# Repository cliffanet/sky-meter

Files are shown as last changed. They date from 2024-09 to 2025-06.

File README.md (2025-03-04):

# Высотомер Sky-Meter

Инструмент для парашютиста - простой высотомер на базе барометра.

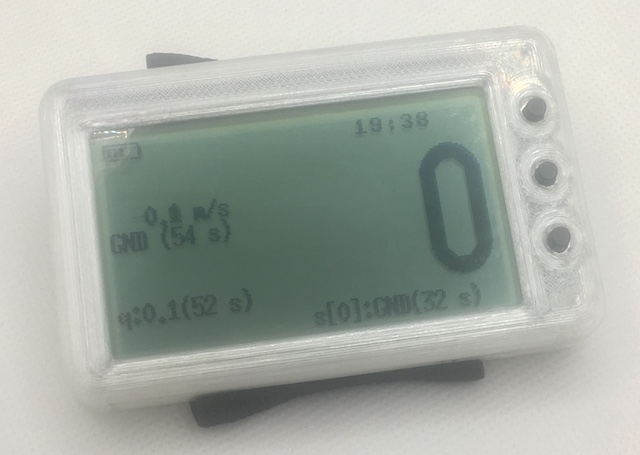
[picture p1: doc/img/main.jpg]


***
## Что умеет

* измерять высоту;
* определять начала подъёма и начало прыжка;
* писать в логбук историю прыжков: время взлёта, высота отделения, высота раскрытия;

***
## Внутри

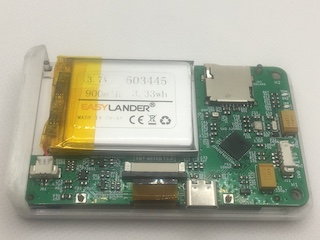
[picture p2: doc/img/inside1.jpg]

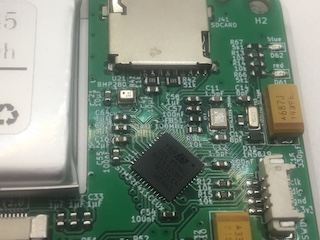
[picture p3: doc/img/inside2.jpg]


***
## Документация

* [Исходники](doc/code.md) - где, что лежит, права на использование, помощь при компиляции.
* [Где скачать](doc/download.md)

***
## Известные проблемы

- повышенное энергопотребление в спящем режиме (850 мкА)

    В первой аппаратной версии применялся чип stm32f473 и энергопотребление всего устройства
    на его основе удалось снизить до 125 мкА, а в выключенном - до 85-90 мкА. И это
    при заявленных в документации 56 мкА (что-то дополнительно подребляет и сама плата).

    А вот на чипе stm32f411 при заявленных в документации 10 мкА получить потребление ниже
    60 мкА так и не удалось - но это на пустой прошивке. На боевой же прошивке почему-то
    не отключаются какие-то узлы, и потребление ~850 мкА. С этим ещё предстоит разобраться.

- нестабильная работа с SD-картой

    Проблема возникает из-за слабого питания, подаваемого на карту. В целях экономии заряда
    батареи питание на SD-карту выведено напрямую с пина микроконтроллера. Применение дополнительного
    транзистора в режиме ключа вызывает проблемы из-за низкого потребляемого тока карты (несколько мА).
    При инициализации карты ток возрастает и питание проседает, из-за чего карта сбрасывается.

    Некоторые карты всё же работают, но таких мало.

    На stm32g4xx работа карт от пина была гораздо стабильнее. Но всё же, на некоторых картах тоже
    были сбои.

    В качестве оперативной меры можно перерезать дорожку, ведущую к пину МК и соединить питание карты
    напрямую на 3.3v. Однако потребление в спящем режиме вместе с SD-картой возрастает до 3 мА.

- отсутствие приложения для импорта логбука

    Разработка отложена на неопределённый срок.

***

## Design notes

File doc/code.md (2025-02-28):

# sky-meter - Исходники

## Открытость проекта

Проект полностью открыт. Закрывать - не планирую. На коммерческую основу ставить - не планирую.

[Репозиторий на github.com](https://github.com/cliffanet/sky-meter)

## Можно ли использовать исходники в своих проектах

Да, никаких возражений против использования исходного кода в своих проектах. Однако, будет лучше, если вы будете ссылаться на использование данного проекта. Это один из важных мотивационных факторов к дальнейшему развитию.

Это относится и к любительским проектам, и к крупным бесплатным, и к коммерческим.

## Где и что находится

* Исходный код прошивки

    Директория [`cube`](https://github.com/cliffanet/sky-meter/tree/master/cube).
    Оптимизировано для среды [STM32CubeMX](https://www.st.com/en/development-tools/stm32cubemx.html).

    - [Как прошить](download.md#обновление-прошивки)
    - [Самостоятельно собрать прошивку](#компиляция-сборка-прошивки-с-помощью-cubemx)

* Исходники электрической схемы и печатной платы

    Всё находится в директории [`hw`](https://github.com/cliffanet/sky-meter/tree/master/hw).
    Среда разработки: [KiCad EDA](https://www.kicad.org/)

    - [Архив с gerber-файлами](../hw/v2.0/sky-meter.v2.0.zip)
    - [Схема принципиальная](../hw/v2.0/sky-meter.v2.0.png)

 

* Исходники 3D-моделей для печати корпуса

    Директория [`box`](https://github.com/cliffanet/sky-meter/tree/master/box).
    Среда: [FreeCAD](https://www.freecad.org/)
    
    Тут же лежат экспортированные в `stl` файлы моделей. В имени файлов зашифровано:
    
    * `top` / `bottom` - верхняя и нижняя часть корпуса.

## Электронные компоненты:

* Дисплей JLX19292G: COG 192x96 на чипе ST75256 c 24-pin шлейфом ([например](https://aliexpress.ru/item/1005002157371258.html))
* Аккумулятор: 503445 900 mAh ([например](https://aliexpress.ru/item/4000288981646.html))
* Микроконтроллер: STM32F411CEU6

## Компиляция (сборка) прошивки с помощью CubeMX

Необходимые пакеты и программы:

- [STM32CubeMX](https://www.st.com/en/development-tools/stm32cubemx.html)

- [arm-none-eabi-gcc](https://developer.arm.com/downloads/-/gnu-rm)

    Для MacOS используйте:

    ```
    brew install --cask gcc-arm-embedded
    ```

- утилита make

Исходный код находится в директории [cube](../cube).

1. Переходим в директорию [cube](../cube).

2. Копируем файл Makefile.stm32f411 в Makefile

3. Открываем файл [sky-meter.stm32f411ceu.ioc](../cube/sky-meter.stm32f411ceu.ioc) в CubeMX.

4. Жмём кнопку "Generate Code".

5. Скачиваем [драйвер SD-карты](http://elm-chan.org/fsw/ff/arc/ff15a.zip) с сайта [elm-chan.org](http://elm-chan.org).

    - берём оттуда только директорию: source
    - переименовываем её в: ff
    - копируем в нашу директорию: [cube/source](../cube/source)
    - удаляем файл cube/source/ff/diskio.c

6. Скачиваем [драйвер дисплея](https://github.com/olikraus/u8g2)

    - берём оттуда только директорию: csrc
    - переименовываем её в: u8g2
    - копируем в нашу директорию: [cube/source](../cube/source)

7. Запускаем командную строку (терминал) в этой же директории.

8. Выполняем:

        make

9. Если всё скомпилировалось успешно, во вложенной директории build будет лежать файл sky-meter.stm32f411ceu.bin

[Инструкция по обновлению прошивки](download.md#обновление-прошивки)

Чтобы изменить язык меню:

    make VLANG=R

или:

    make VLANG=E

## Предыдущая аппаратная версия

- [плата v1.0](../hw/v1.0/sky-meter.v1.0.zip)
- CubeMX файлы:
    - [sky-meter.stm32g431cbu.ioc](../cube/sky-meter.stm32g431cbu.ioc) и [Makefile.stm32g431](../cube/Makefile.stm32g431)
    - [sky-meter.stm32g473ceu.ioc](../cube/sky-meter.stm32g473ceu.ioc) и [Makefile.stm32g473](../cube/Makefile.stm32g473)

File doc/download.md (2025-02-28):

# Скачивание файлов

Стабильная версия прошивки:

* RU: [sky-meter.stm32f411ceu.v1.00.ru.bin](https://github.com/cliffanet/sky-meter/releases/download/v1.00/sky-meter.stm32f411ceu.v1.00.ru.bin)
* EN: [sky-meter.stm32f411ceu.v1.00.en.bin](https://github.com/cliffanet/sky-meter/releases/download/v1.00/sky-meter.stm32f411ceu.v1.00.en.bin)

## Обновление прошивки

Неодходимое оборудование:

- SWD-кабель

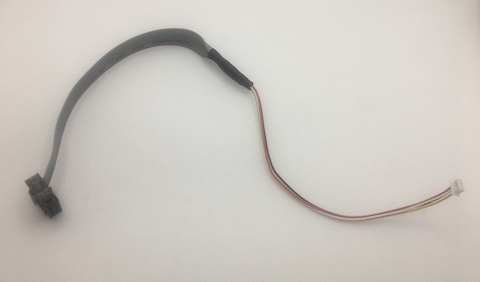
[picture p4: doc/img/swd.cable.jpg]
    

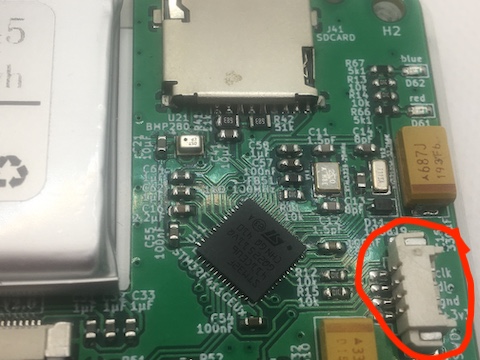
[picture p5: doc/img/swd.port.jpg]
    

- программатор ST-Link v.2

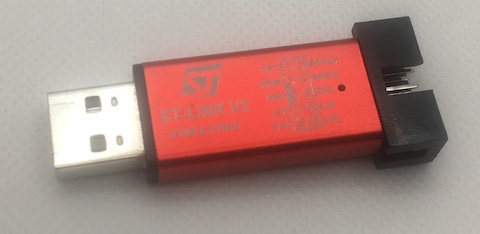
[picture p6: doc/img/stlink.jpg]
    

- [Утилита взаимодействия по SWD-порту](https://www.st.com/en/development-tools/stm32cubeprog.html)

## История версий

[История версий и самые свежие файлы](https://github.com/cliffanet/sky-meter/releases)

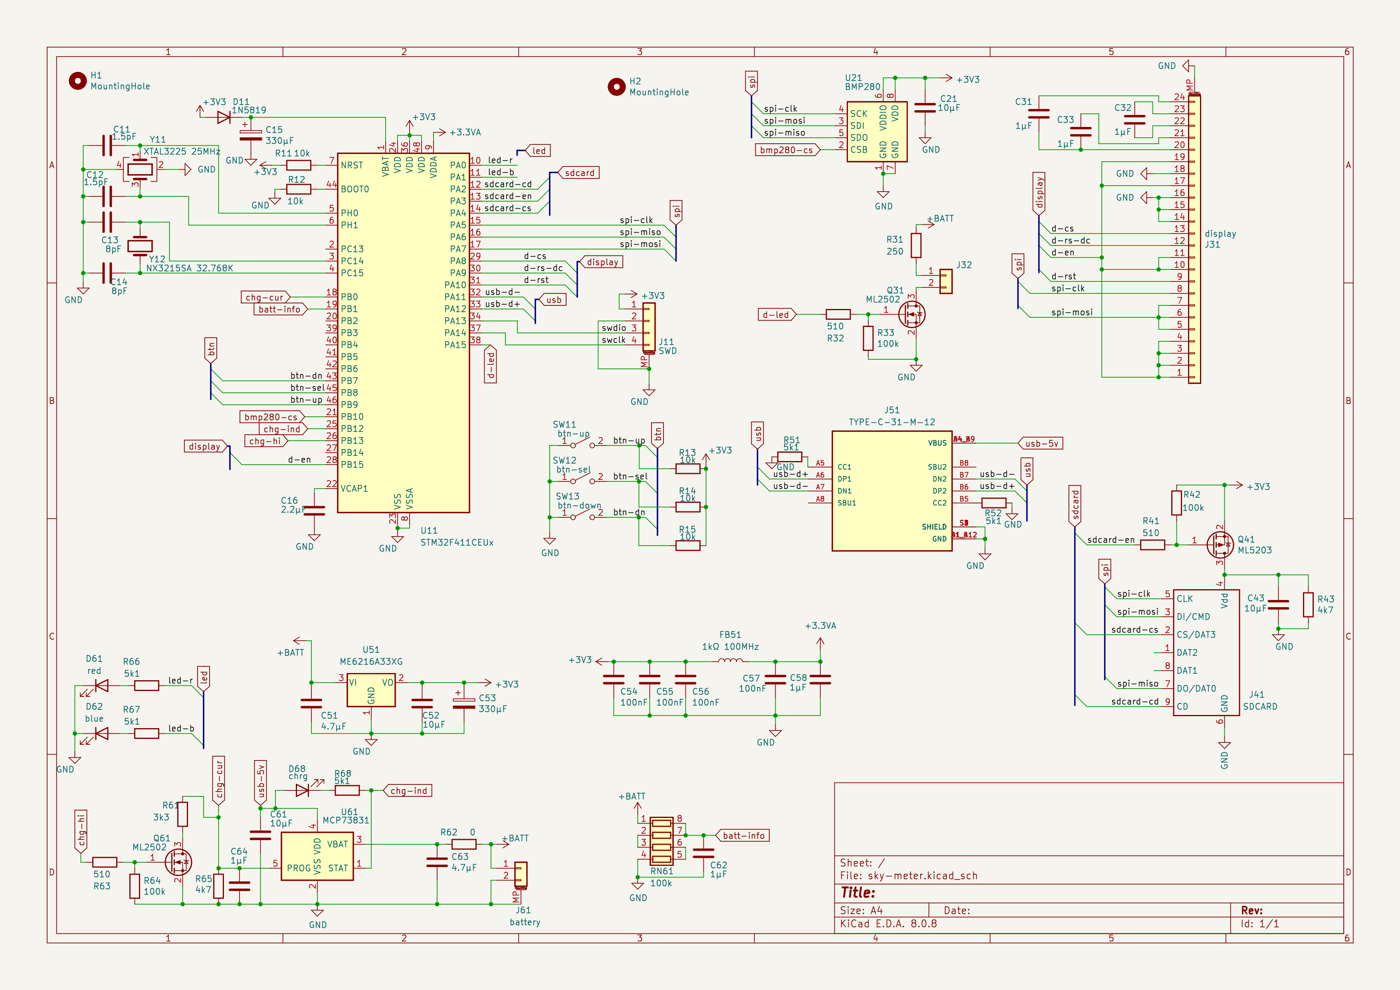
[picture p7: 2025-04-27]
hw/v2.1/sky-meter.v2.1.png

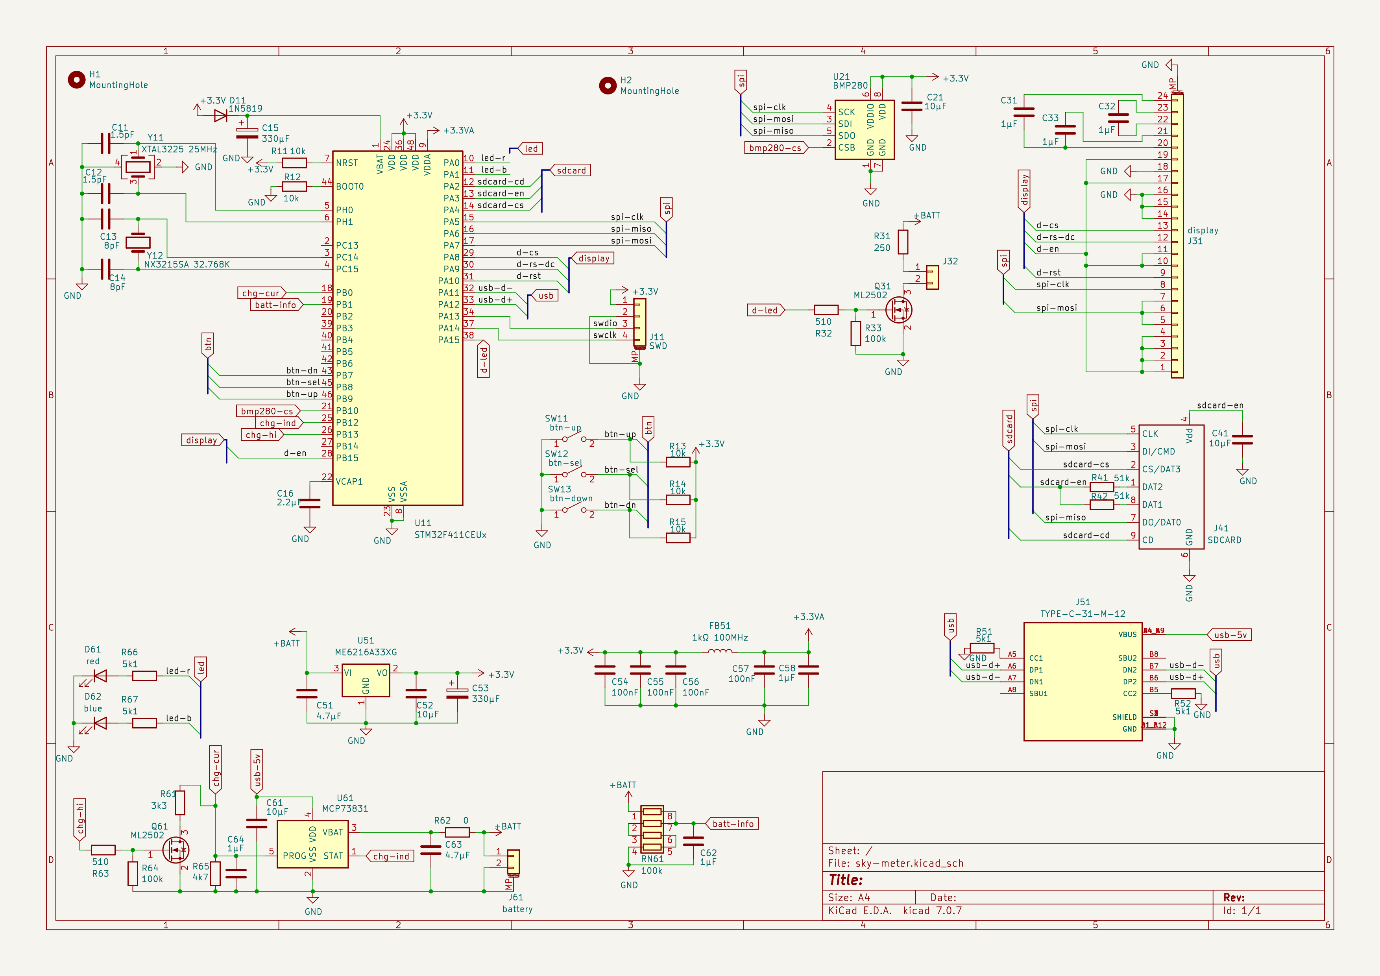
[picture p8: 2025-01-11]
hw/sky-meter.v2.0.png

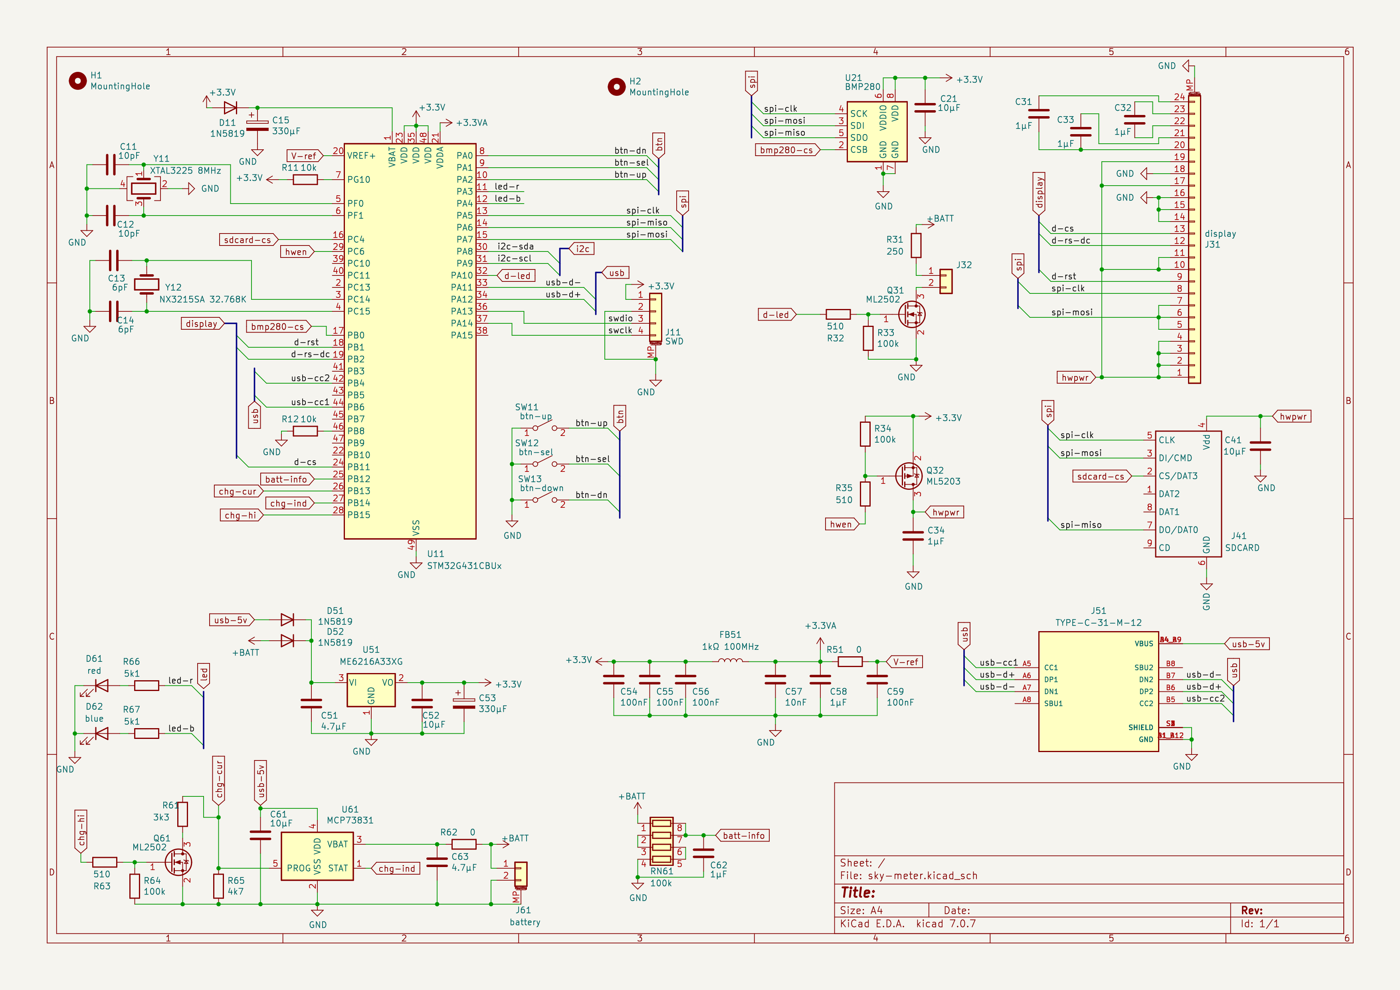
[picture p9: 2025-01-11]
hw/sky-meter.v1.0.png

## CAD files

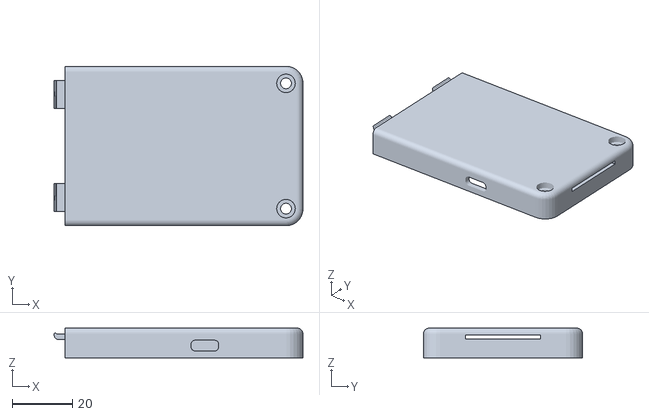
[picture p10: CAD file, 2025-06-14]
box/sky-meter-w-down.stl
82.7 x 52.9 x 9.90

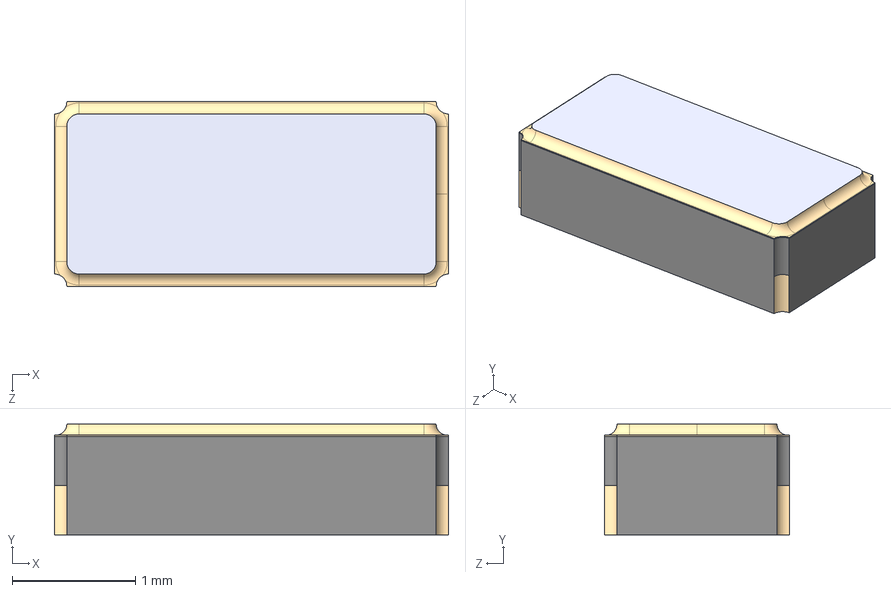
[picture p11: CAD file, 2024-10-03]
hw/sym/NX3215SA-32.768K-STD-MUA-14/NX3215SA-32.768K-STD-MUA-14.step
3.20 x 0.9 x 1.50 mm

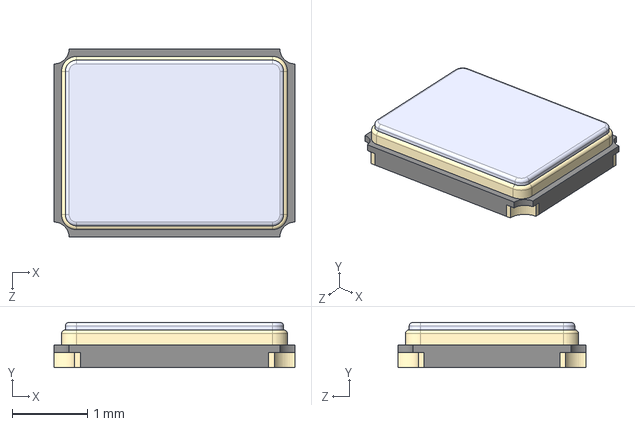
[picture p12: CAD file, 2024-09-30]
hw/sym/TSX-3225_16.0000MF18X-AC3/TSX-3225_16.0000MF18X-AC3.step
3.20 x 0.6 x 2.50 mm

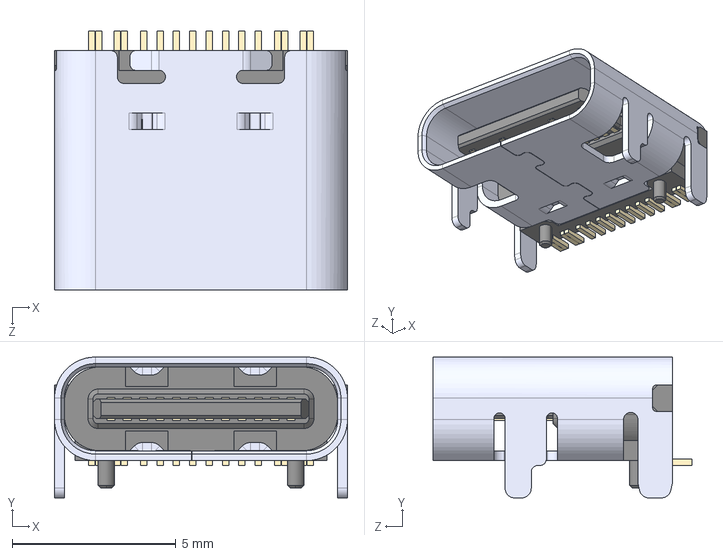
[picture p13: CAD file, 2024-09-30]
hw/sym/TYPE-C-31-M-12/TYPE-C-31-M-12.step
8.94 x 4.30 x 7.90 mm

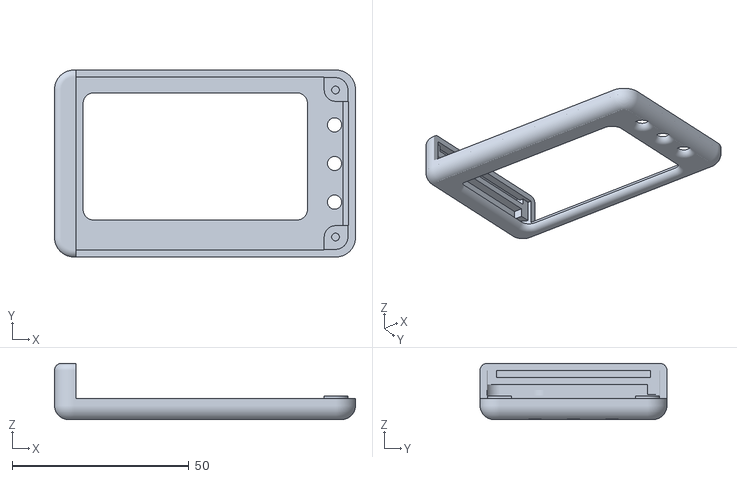
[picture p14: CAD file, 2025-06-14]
box/sky-meter-h-up.stl
85.2 x 52.9 x 15.9

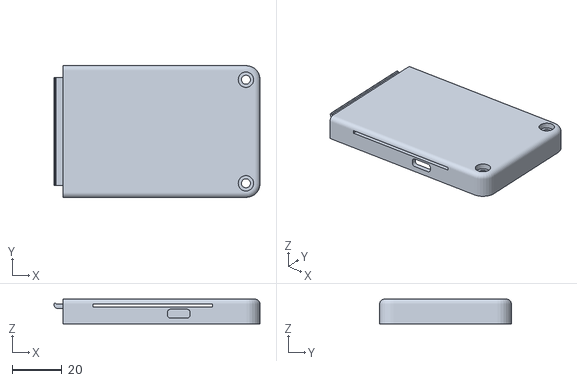
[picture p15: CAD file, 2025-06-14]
box/sky-meter-h-down.stl
82.7 x 52.9 x 9.90

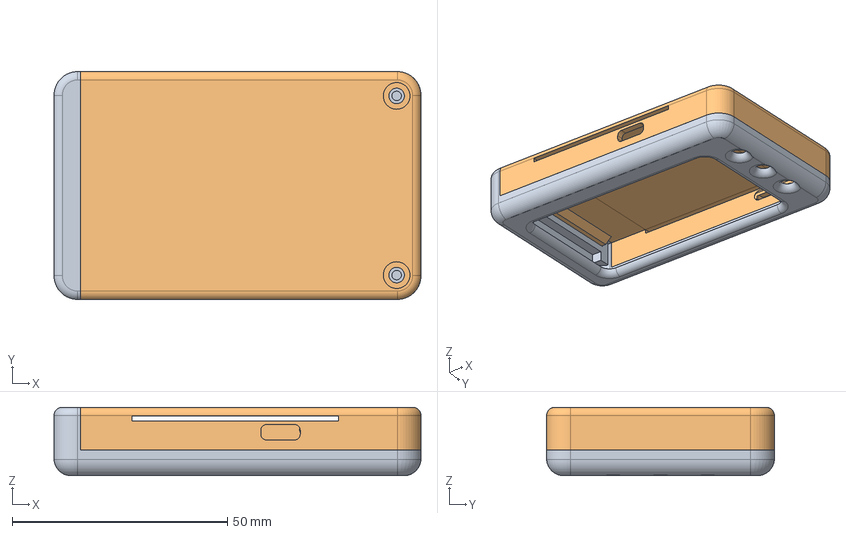
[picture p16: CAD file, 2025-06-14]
box/sky-meter.FCStd
85.2 x 52.9 x 15.9 mm
h-up
h-down

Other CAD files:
box/sky-meter-w-up.stl

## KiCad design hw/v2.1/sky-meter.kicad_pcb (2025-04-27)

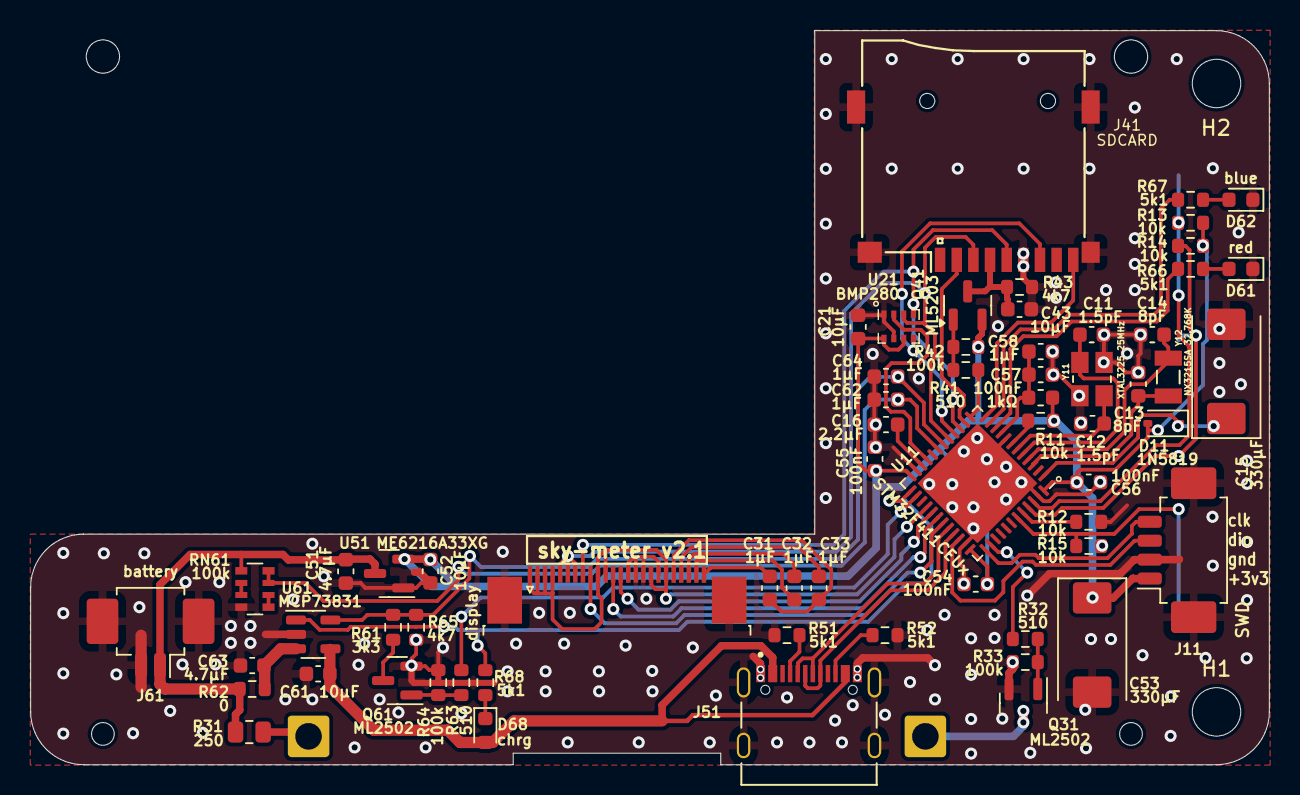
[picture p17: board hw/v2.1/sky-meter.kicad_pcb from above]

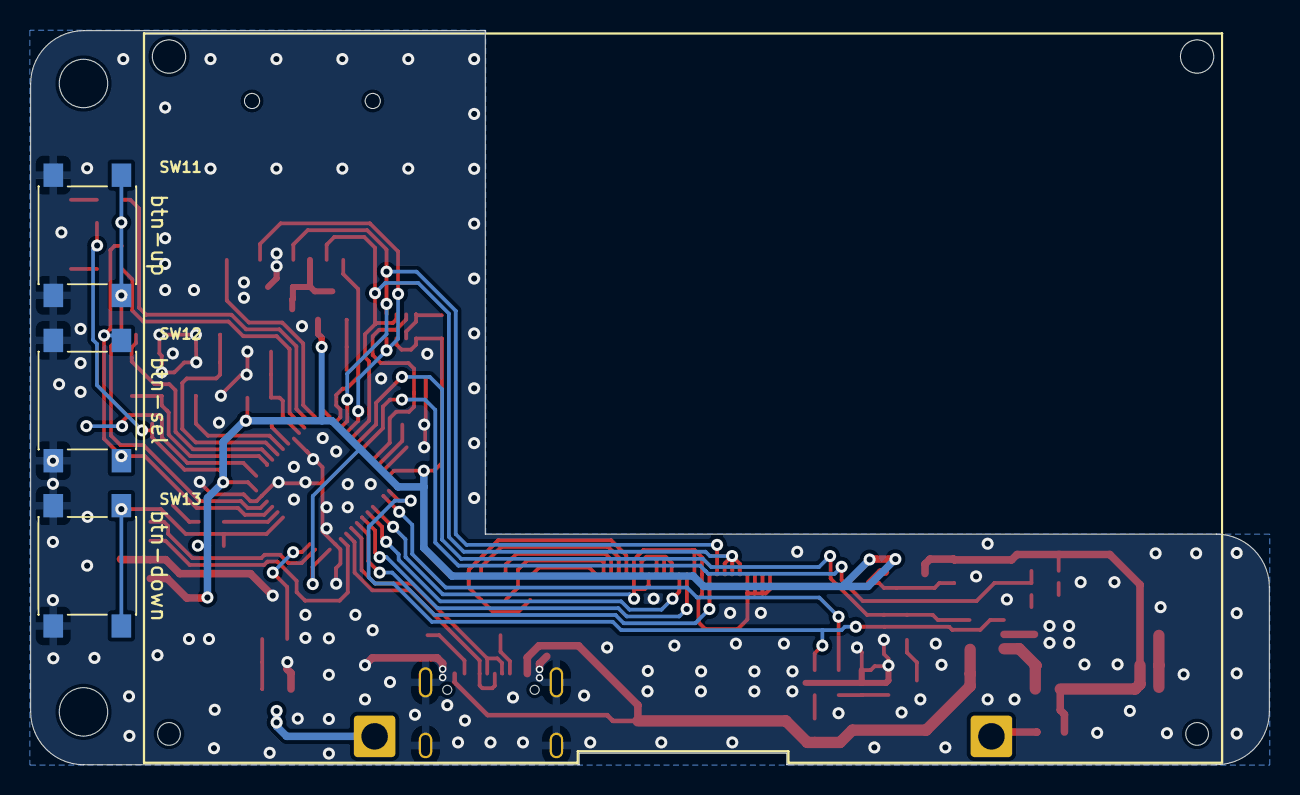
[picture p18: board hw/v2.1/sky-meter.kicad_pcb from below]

Board: 2 copper layers, 81.9 x 48.5 mm, 70 parts (3 on the bottom side), 58 nets.

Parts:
C11, C12: 1.5pF; C_0603_1608Metric
C13, C14: 8pF; C_0603_1608Metric
C15, C53: 330μF; CP_EIA-7343-20_Kemet-V
C16: 2.2μF; C_0603_1608Metric
C21, C43, C52, C61: 10μF; C_0603_1608Metric
C31, C32, C33, C58, C62, C64: 1μF; C_0603_1608Metric
C51, C63: 4.7μF; C_0603_1608Metric
C54, C55, C56, C57: 100nF; C_0603_1608Metric
D11: 1N5819; D_SOD-323
D61: red; LED_0603_1608Metric
D62: blue; LED_0603_1608Metric
D68: chrg; LED_0603_1608Metric
FB51: 1kΩ; L_0603_1608Metric
H1, H2: MountingHole; MountingHole_3.2mm_M3
J11: SWD; Molex_PicoBlade_53261-0471_1x04-1MP_P1.25mm_Horizontal
J31: display; TE_2-1734839-4_1x24-1MP_P0.5mm_Horizontal
J32: display-128x64
J41: SDCARD; Conn_uSDcard
J51: TYPE-C-31-M-12; HRO_TYPE-C-31-M-12
J61: battery; Molex_PicoBlade_53261-0271_1x02-1MP_P1.25mm_Horizontal
Q31, Q61: ML2502; SOT-23
Q41: ML5203; SOT-23
R11, R12, R13, R14, R15: 10k; R_0603_1608Metric
R31: 250; R_0805_2012Metric
R32, R41, R63: 510; R_0603_1608Metric
R33, R42, R64: 100k; R_0603_1608Metric
R43, R65: 4k7; R_0603_1608Metric
R51, R52, R66, R67, R68: 5k1; R_0603_1608Metric
R61: 3k3; R_0603_1608Metric
R62: 0; R_0603_1608Metric
RN61: 100k; R_Array_Convex_4x0603
SW11: btn-up; SW_Push_1P1T_NO_6x6mm_H9.5mm
SW12: btn-sel; SW_Push_1P1T_NO_6x6mm_H9.5mm
SW13: btn-down; SW_Push_1P1T_NO_6x6mm_H9.5mm
U11: STM32F411CEUx; QFN-48-1EP_7x7mm_P0.5mm_EP5.6x5.6mm
U21: BMP280; Bosch_LGA-8_2x2.5mm_P0.65mm_ClockwisePinNumbering
U51: ME6216A33XG; SOT-23
U61: MCP73831; SOT-23-5
Y11: XTAL3225 25MHz; XTAL_TSX-3225_16.0000MF18X-AC3
Y12: NX3215SA 32.768K; XTAL_NX3215SA-32.768K-STD-MUA-14

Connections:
+3.3VA: C57.2, C58.2, FB51.2, U11.9 (VDDA)
+3V3: C21.1, C52.2, C53.1, C54.1, C55.1, C56.1, D11.2 (A), FB51.1, J11.1, Q41.2 (S), R11.1, R13.1, R14.1, R15.1, R42.2, U11.24 (VDD), U11.36 (VDD), U11.48 (VDD), U21.6 (VDDIO), U21.8 (VDD), U51.2 (VO)
+BATT: C51.1, J61.1, R31.2, R62.2, RN61.1 (R1.1), U51.3 (VI)
/btn-dn: R15.2, SW13.2 (B), U11.43 (PB7)
/btn-sel: R14.2, SW12.2 (B), U11.45 (PB8)
/btn-up: R13.2, SW11.2 (B), U11.46 (PB9)
/d-cs: J31.13, U11.29 (PA8)
/d-en: J31.1, J31.2, J31.3, J31.4, J31.10, J31.11, J31.17, J31.19, U11.28 (PB15)
/d-rs-dc: J31.12, U11.30 (PA9)
/d-rst: J31.9, U11.31 (PA10)
/led-b: R67.2, U11.11 (PA1)
/led-r: R66.2, U11.10 (PA0)
/sdcard-cd: J41.9 (CD), U11.12 (PA2)
/sdcard-cs: J41.2 (CS/DAT3), U11.14 (PA4)
/sdcard-en: R41.2, U11.13 (PA3)
/spi-clk: J31.8, J41.5 (CLK), U11.15 (PA5), U21.4 (SCK)
/spi-miso: J41.7 (DO/DAT0), U11.16 (PA6), U21.5 (SDO)
/spi-mosi: J31.5, J31.6, J31.7, J41.3 (DI/CMD), U11.17 (PA7), U21.3 (SDI)
/swclk: J11.4, U11.37 (PA14)
/swdio: J11.3, U11.34 (PA13)
/usb-d+: J51.A6 (DP1), J51.B6 (DP2), U11.33 (PA12)
/usb-d-: J51.A7 (DN1), J51.B7 (DN2), U11.32 (PA11)
GND: C11.1, C12.1, C13.1, C14.1, C15.2, C16.2, C21.2, C43.1, C51.2, C52.1, C53.2, C54.2, C55.2, C56.2, C57.1, C58.1, C61.2, C62.2, C63.2, C64.2, D61.1 (K), D62.1 (K), J11.2, J11.MP (MountPin), J31.14, J31.15, J31.16, J31.18, J31.MP (MountPin), J41.6 (GND), J51.A1_B12 (GND), J51.B1_A12 (GND), J51.S1 (SHIELD), J51.S2 (SHIELD), J51.S3 (SHIELD), J51.S4 (SHIELD), J61.2, J61.MP (MountPin), Q31.2 (S), Q61.2 (S), R12.2, R33.2, R43.2, R51.1, R52.2, R64.2, R65.2, RN61.4 (R4.1), SW11.1 (A), SW12.1 (A), SW13.1 (A), U11.8 (VSSA), U11.23 (VSS), U11.35 (VSS), U11.47 (VSS), U11.49 (VSS), U21.1 (GND), U21.7 (GND), U51.1 (GND), U61.2 (VSS), Y11.2, Y11.4
unnamed: C15.1, D11.1 (K), U11.1 (VBAT)
unnamed: D61.2 (A), R66.1
unnamed: D62.2 (A), R67.1
unnamed: D68.1 (K), R68.1
unnamed: C31.1, C33.1, J31.20
unnamed: C33.2, J31.21
unnamed: C32.2, J31.22
unnamed: C32.1, J31.23
unnamed: C31.2, J31.24
unnamed: J32.1, R31.1
unnamed: J32.2, Q31.3 (D)
unnamed: C43.2, J41.4 (Vdd), Q41.3 (D), R43.1
unnamed: J51.A5 (CC1), R51.2
unnamed: J51.B5 (CC2), R52.1
unnamed: Q31.1 (G), R32.1, R33.1
unnamed: Q41.1 (G), R41.1, R42.1
unnamed: Q61.3 (D), R61.2
unnamed: Q61.1 (G), R63.1, R64.1
unnamed: RN61.2 (R2.1), RN61.3 (R3.1)
unnamed: RN61.5 (R4.2), RN61.6 (R3.2)
unnamed: R12.1, U11.44 (BOOT0)
unnamed: R11.2, U11.7 (NRST)
unnamed: C13.2, U11.3 (PC14), Y12.2
unnamed: C14.2, U11.4 (PC15), Y12.1
unnamed: C11.2, U11.5 (PH0), Y11.1
unnamed: C12.2, U11.6 (PH1), Y11.3
unnamed: C16.1, U11.22 (VCAP1)
unnamed: C63.1, R62.1, U61.3 (VBAT)
batt-info: C62.1, RN61.7 (R2.2), RN61.8 (R1.2), U11.19 (PB1)
bmp280-cs: U11.21 (PB10), U21.2 (CSB)
chg-cur: C64.1, R61.1, R65.1, U11.18 (PB0), U61.5 (PROG)
chg-hi: R63.2, U11.26 (PB13)
chg-ind: R68.2, U11.25 (PB12), U61.1 (STAT)
d-led: R32.2, U11.38 (PA15)
usb-5v: C61.1, D68.2 (A), J51.A4_B9 (VBUS), J51.B4_A9 (VBUS), U61.4 (VDD)

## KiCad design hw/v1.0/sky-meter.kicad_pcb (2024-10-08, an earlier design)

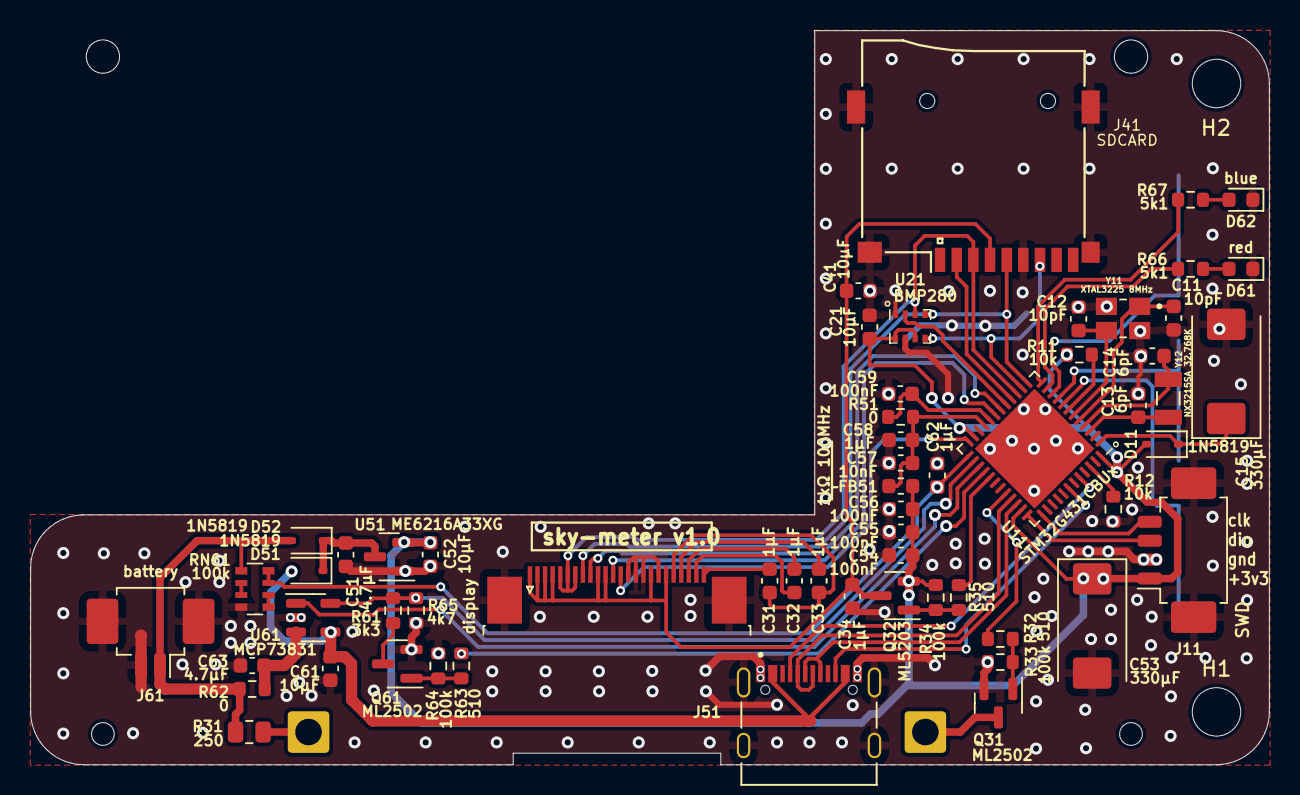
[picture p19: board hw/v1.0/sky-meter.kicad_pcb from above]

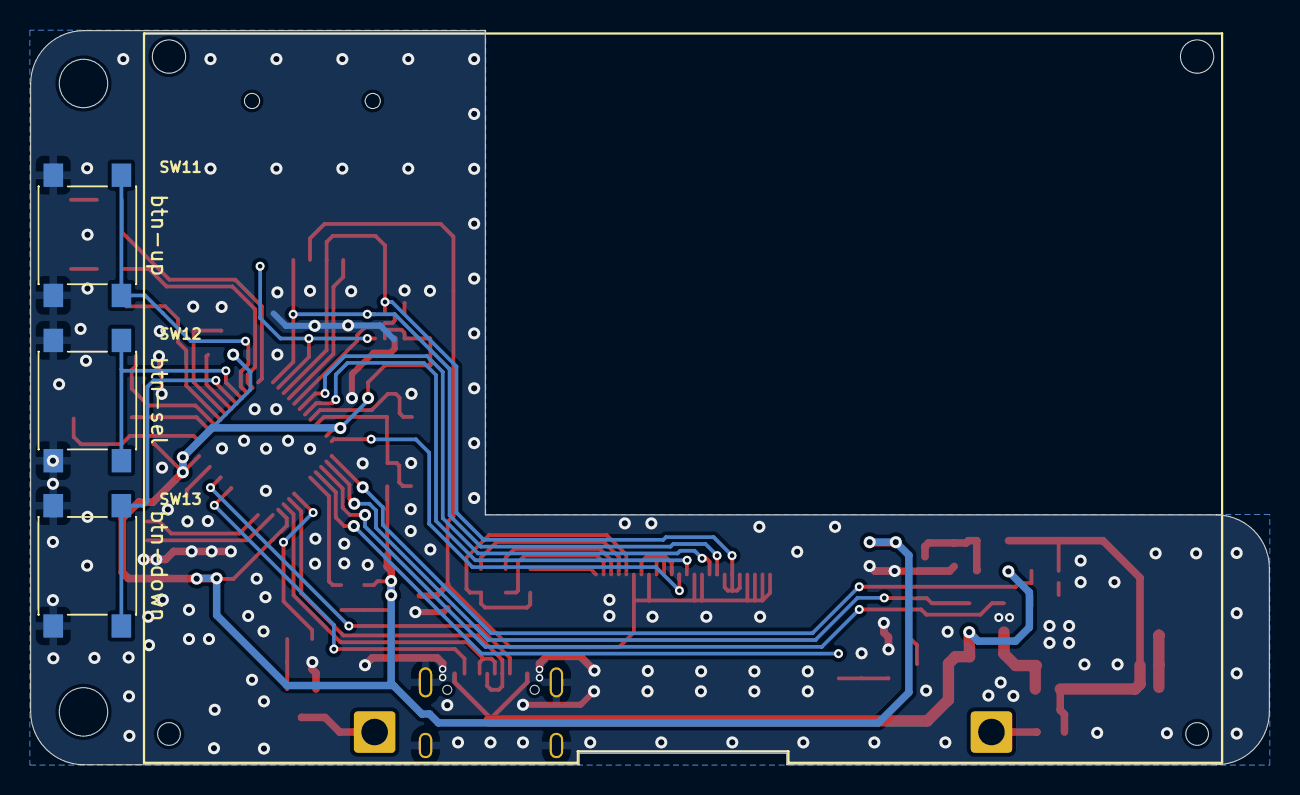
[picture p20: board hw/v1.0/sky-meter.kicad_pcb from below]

Board: 2 copper layers, 81.9 x 48.5 mm, 65 parts (3 on the bottom side), 56 nets.

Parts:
C11, C12: 10pF; C_0603_1608Metric
C13, C14: 6pF; C_0603_1608Metric
C15, C53: 330μF; CP_EIA-7343-20_Kemet-V
C21, C41, C52, C61: 10μF; C_0603_1608Metric
C31, C32, C33, C34, C58, C62: 1μF; C_0603_1608Metric
C51, C63: 4.7μF; C_0603_1608Metric
C54, C55, C56, C59: 100nF; C_0603_1608Metric
C57: 10nF; C_0603_1608Metric
D11, D51, D52: 1N5819; D_SOD-323
D61: red; LED_0603_1608Metric
D62: blue; LED_0603_1608Metric
FB51: 1kΩ 100MHz; L_0603_1608Metric
H1, H2: MountingHole; MountingHole_3.2mm_M3
J11: SWD; Molex_PicoBlade_53261-0471_1x04-1MP_P1.25mm_Horizontal
J31: display; TE_2-1734839-4_1x24-1MP_P0.5mm_Horizontal
J32: display-256x192
J41: SDCARD; Conn_uSDcard
J51: TYPE-C-31-M-12; HRO_TYPE-C-31-M-12
J61: battery; Molex_PicoBlade_53261-0271_1x02-1MP_P1.25mm_Horizontal
Q31, Q61: ML2502; SOT-23
Q32: ML5203; SOT-23
R11, R12: 10k; R_0603_1608Metric
R31: 250; R_0805_2012Metric
R32, R35, R63: 510; R_0603_1608Metric
R33, R34, R64: 100k; R_0603_1608Metric
R51, R62: 0; R_0603_1608Metric
R61: 3k3; R_0603_1608Metric
R65: 4k7; R_0603_1608Metric
R66, R67: 5k1; R_0603_1608Metric
RN61: 100k; R_Array_Convex_4x0603
SW11: btn-up; SW_Push_1P1T_NO_6x6mm_H9.5mm
SW12: btn-sel; SW_Push_1P1T_NO_6x6mm_H9.5mm
SW13: btn-down; SW_Push_1P1T_NO_6x6mm_H9.5mm
U11: STM32G431CBUx; QFN-48-1EP_7x7mm_P0.5mm_EP5.6x5.6mm
U21: BMP280; Bosch_LGA-8_2x2.5mm_P0.65mm_ClockwisePinNumbering
U51: ME6216A33XG; SOT-23
U61: MCP73831; SOT-23-5
Y11: XTAL3225 8MHz; XTAL_TSX-3225_16.0000MF18X-AC3
Y12: NX3215SA 32.768K; XTAL_NX3215SA-32.768K-STD-MUA-14

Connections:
+3.3VA: C57.1, C58.1, FB51.2, R51.1, U11.21 (VDDA)
+3V3: C21.1, C52.2, C53.1, C54.1, C55.1, C56.1, D11.2 (A), FB51.1, J11.1, Q32.2 (S), R11.1, R34.1, U11.23 (VDD), U11.35 (VDD), U11.48 (VDD), U21.6 (VDDIO), U21.8 (VDD), U51.2 (VO)
+BATT: D52.2 (A), J61.1, R31.2, R62.2, RN61.1 (R1.1)
/btn-dn: SW13.2 (B), U11.8 (PA0)
/btn-sel: SW12.2 (B), U11.9 (PA1)
/btn-up: SW11.2 (B), U11.10 (PA2)
/d-cs: J31.13, U11.24 (PB11)
/d-rs-dc: J31.12, U11.19 (PB2)
/d-rst: J31.9, U11.18 (PB1)
/led-b: R67.2, U11.12 (PA4)
/led-r: R66.2, U11.11 (PA3)
/spi-clk: J31.8, J41.5 (CLK), U11.13 (PA5), U21.4 (SCK)
/spi-miso: J41.7 (DO/DAT0), U11.14 (PA6), U21.5 (SDO)
/spi-mosi: J31.5, J31.6, J31.7, J41.3 (DI/CMD), U11.15 (PA7), U21.3 (SDI)
/swclk: J11.4, U11.37 (PA14)
/swdio: J11.3, U11.36 (PA13)
/usb-cc1: J51.A5 (CC1), U11.44 (PB6)
/usb-cc2: J51.B5 (CC2), U11.42 (PB4)
/usb-d+: J51.A6 (DP1), J51.B6 (DP2), U11.34 (PA12)
/usb-d-: J51.A7 (DN1), J51.B7 (DN2), U11.33 (PA11)
GND: C11.1, C12.1, C13.1, C14.1, C15.2, C21.2, C34.2, C41.2, C51.2, C52.1, C53.2, C54.2, C55.2, C56.2, C57.2, C58.2, C59.2, C61.2, C62.2, C63.2, D61.1 (K), D62.1 (K), J11.2, J11.MP (MountPin), J31.14, J31.15, J31.16, J31.18, J31.MP (MountPin), J41.6 (GND), J51.A1_B12 (GND), J51.B1_A12 (GND), J51.S1 (SHIELD), J51.S2 (SHIELD), J51.S3 (SHIELD), J51.S4 (SHIELD), J61.2, J61.MP (MountPin), Q31.2 (S), Q61.2 (S), R12.1, R33.2, R64.2, R65.2, RN61.4 (R4.1), SW11.1 (A), SW12.1 (A), SW13.1 (A), U11.49 (VSS), U21.1 (GND), U21.7 (GND), U51.1 (GND), U61.2 (VSS), Y11.2, Y11.4
unnamed: C15.1, D11.1 (K), U11.1 (VBAT)
unnamed: C51.1, D51.1 (K), D52.1 (K), U51.3 (VI)
unnamed: D61.2 (A), R66.1
unnamed: D62.2 (A), R67.1
unnamed: C31.1, C33.1, J31.20
unnamed: C33.2, J31.21
unnamed: C32.2, J31.22
unnamed: C32.1, J31.23
unnamed: C31.2, J31.24
unnamed: J32.1, R31.1
unnamed: J32.2, Q31.3 (D)
unnamed: Q31.1 (G), R32.1, R33.1
unnamed: Q32.1 (G), R34.2, R35.2
unnamed: Q61.3 (D), R61.2
unnamed: Q61.1 (G), R63.1, R64.1
unnamed: RN61.2 (R2.1), RN61.3 (R3.1)
unnamed: RN61.5 (R4.2), RN61.6 (R3.2)
unnamed: R12.2, U11.46 (PB8)
unnamed: C13.2, U11.3 (PC14), Y12.2
unnamed: C14.2, U11.4 (PC15), Y12.1
unnamed: C11.2, U11.5 (PF0), Y11.1
unnamed: C12.2, U11.6 (PF1), Y11.3
unnamed: R11.2, U11.7 (PG10)
unnamed: C63.1, R62.1, U61.3 (VBAT)
V-ref: C59.1, R51.2, U11.20 (VREF+)
batt-info: C62.1, RN61.7 (R2.2), RN61.8 (R1.2), U11.25 (PB12)
bmp280-cs: U11.17 (PB0), U21.2 (CSB)
chg-cur: R61.1, R65.1, U11.26 (PB13), U61.5 (PROG)
chg-hi: R63.2, U11.28 (PB15)
chg-ind: U11.27 (PB14), U61.1 (STAT)
d-led: R32.2, U11.32 (PA10)
hwen: R35.1, U11.29 (PC6)
hwpwr: C34.1, C41.1, J31.1, J31.2, J31.3, J31.4, J31.10, J31.11, J31.17, J31.19, J41.4 (Vdd), Q32.3 (D)
sdcard-cs: J41.2 (CS/DAT3), U11.16 (PC4)
usb-5v: C61.1, D51.2 (A), J51.A4_B9 (VBUS), J51.B4_A9 (VBUS), U61.4 (VDD)

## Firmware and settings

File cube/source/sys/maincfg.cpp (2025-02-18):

/*
    Config
*/

#include "maincfg.h"
#include "stm32drv.h"
#include "cks.h"
#include "iflash.h"
#include "log.h"

#include <string.h>
    
Config cfg;

#if HWVER < 2

typedef struct __attribute__((__packed__)) {
    uint8_t id;
    uint8_t ver;
    uint16_t sz;
} hdr_t;

static int efind(hdr_t &h) {
    uint32_t beg = CONFIG_ADDR, p = beg;
    // особенности записи:
    //      - запись словами - _FLASH_WBLK_SIZE = 8 байт (необходимо выравнивание данных)
    //      - после erase каждое слово пишется только один раз, следующая запись возможна только после erase
    // формат хранения:
    //      - 1 слово (8 байт) - всегда индикатор, что следом актуальные данные или пусто.
    //          при сохранении данных мы в это слово ничего не пишем
    //      - 4 байта - заголовок hdr_t
    //      - данные
    //      - 2 байта - контрольная сумма.
    //
    // при следующей записи помечаем 1 слово-индикатор как 0xef.... - это значит, что следом
    // идёт неактуальная запись, которую надо пропустить.
    //
    // - в любой непонятной ситуации возвращаем -1
    // - если найдена валидная запись, возвращаем
    while (p+_FLASH_WBLK_SIZE*2 < CONFIG_AEND) {
        auto ff = *reinterpret_cast<__IO uint64_t *>(p);
        bool ok = ff == 0xffffffffffffffff;
        if (!ok && (ff != 0xefffffffffffffff))
            return -1;
        p += sizeof(uint64_t);
        h = *const_cast<hdr_t *>(reinterpret_cast<__IO hdr_t *>(p));
        if ((h.id != CONFIG_HDR) || (h.ver < 1) || (h.ver > CONFIG_VER) || (h.sz < 4) || (h.sz > 2048))
            return -1;
        if (ok)
            return iflash::validcks(p + sizeof(hdr_t), h.sz) ? p - beg : -1;
        else
            p += _FLASH_WBLK_ALIGN(sizeof(hdr_t) + h.sz + sizeof(cks_t));
    }

    return -1;
}

#endif // if HWVER < 2

void Config::init() {

#if HWVER < 2

    hdr_t h;
    // ищем валидный блок с данными
    auto p = efind(h);
    data_t d;
    if (p > 0) {
        CONSOLE("config found on: 0x%04x", p);
        uint16_t sz = h.sz < sizeof(data_t) ? h.sz : sizeof(data_t);
        memcpy(&d, const_cast<uint8_t *>(reinterpret_cast<__IO uint8_t *>(CONFIG_ADDR + p + sizeof(hdr_t))), sz);
    }

#else // if HWVER < 2

    data_t d;

    auto r = iflash::last(iflash::TYPE_CONFIG);
    if (r.read(d)) {
        CONSOLE("config found on: 0x%06x", r.addr()-_FLASH_BASE);
    }

#endif

    cfg._d      = d;
    cfg._chg    = false;
}

#if HWVER < 2

static bool esave(int p, const Config::data_t &data) {
    if (p > 0) {
        p += CONFIG_ADDR;
        // а если валидный блок всё же найден,
        // то пометим его как "пропустить"...
        auto st = HAL_FLASH_Program(FLASH_TYPEPROGRAM_DOUBLEWORD, p-_FLASH_WBLK_SIZE, 0xefffffffffffffff);
        CONSOLE("HAL_FLASH_Program: %d, errno: %d", st, st == HAL_OK ? 0 : HAL_FLASH_GetError());
        if (st != HAL_OK)
            return false;
        
        // а под запись будем использовать уже следующий блок, выровненный до _FLASH_WBLK_SIZE
        auto sz = reinterpret_cast<__IO hdr_t *>(p)->sz;
        p += _FLASH_WBLK_ALIGN(sizeof(hdr_t) + sz + sizeof(cks_t));

        if (p + _FLASH_WBLK_SIZE + _FLASH_WBLK_ALIGN(sizeof(hdr_t) + sizeof(Config::data_t) + sizeof(cks_t)) > CONFIG_AEND) {
            CONSOLE("flash-page fulled, need erase!");
            p = -1;
        }
    }
    if (p > 0) {
        // слово индикатор - обязан быть как нетронутый ещё при записи
        if (_FLASH_WBLK_ISERASE(p))
            p += _FLASH_WBLK_SIZE;
        else {
            CONSOLE("free-indicator no nulled, need erase!");
            p = -1;
        }
    }
    if (p < 0) {
        // в случае, если мы не нашли валидный блок
        // или новый после него не влезет,
        // то надо выполнить стирание всей страницы
        if (!iflash::erase(CONFIG_ADDR))
            return false;
        p = CONFIG_ADDR + _FLASH_WBLK_SIZE;
    }
    
    // подготавливаем данные под сохранение,
    // их надо выровнять до _FLASH_WBLK_SIZE
    struct __attribute__((__packed__)) {
        hdr_t h;
        Config::data_t d;
    } d = {
        .h = {
            .id     = CONFIG_HDR,
            .ver    = CONFIG_VER,
            .sz     = sizeof(Config::data_t)
        },
        .d = data
    };

    // пишем подготовленные данные
    CONSOLE("config saving to: 0x%06x (0x%04x)", p-_FLASH_WBLK_SIZE, p-CONFIG_ADDR);
    return iflash::writecks(p, d, sizeof(hdr_t));
}

#endif // HWVER < 2

bool Config::save() {
    if (!_chg)
        return true;

#if HWVER < 2

    hdr_t h;
    // ищем валидный блок с данными
    auto p = efind(h);

    if ((p >= 0) && (CONFIG_ADDR + p + (sizeof(hdr_t) + sizeof(cks_t))*2 + h.sz + sizeof(Config::data_t) > CONFIG_AEND))
        // если блок валидный, но после него новый всё равно не влезет
        p = -1;
    
    // далее, приступаем к записи, для этого
    // надо разблокировать флеш-память
    iflash::Unlocker _l;

    if (!_l || !esave(p, _d))
        return false;

#else // if HWVER < 2

    auto r = iflash::save(_FLASH_TYPE_CONFIG, _d);
    if (r) {
        CONSOLE("config saving to: page=0x%06x, addr=0x%04x", r.page().num(), r.a());
    }
    else {
        CONSOLE("config saving FAIL");
        return false;
    }

#endif // if HWVER < 2
    
    _chg = false;
    return true;
}

const Config::data_t* Config::operator->() const {
    return &_d;
}

 Config::data_t *Config::operator*() {
    _chg = true;
    return &_d;
}

bool Config::resetdefault() {
    data_t d;
    cfg._d      = d;
    cfg._chg    = true;

    return save();
}

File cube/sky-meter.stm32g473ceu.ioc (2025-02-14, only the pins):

Mcu.UserName=STM32G473CEUx
PA0.GPIO_Label=btn dn
PA0.Signal=GPXTI0
PA1.GPIO_Label=btn sel
PA1.Signal=GPXTI1
PA10.GPIO_Label=display light
PA10.Signal=GPIO_Output
PA11.Signal=USB_DM
PA12.Signal=USB_DP
PA2.GPIO_Label=btn up
PA2.Signal=GPXTI2
PA3.GPIO_Label=led red
PA3.Signal=GPIO_Output
PA4.GPIO_Label=led blue
PA4.Signal=GPIO_Output
PA5.Signal=SPI1_SCK
PA6.Signal=SPI1_MISO
PA7.Signal=SPI1_MOSI
PB0.GPIO_Label=bmp280 cs
PB0.Signal=GPIO_Output
PB1.GPIO_Label=display rst
PB1.Signal=GPIO_Output
PB11.GPIO_Label=display cs
PB11.Signal=GPIO_Output
PB12.GPIO_Label=batt info
PB12.Signal=ADC1_IN11
PB14.GPIO_Label=chg ind
PB14.Signal=GPIO_Input
PB15.GPIO_Label=chg hi
PB15.Signal=GPIO_Output
PB2.GPIO_Label=display rs-dc
PB2.Signal=GPIO_Output
PB4.Signal=UCPD1_CC2
PB6.Signal=UCPD1_CC1
PC14-OSC32_IN.Signal=RCC_OSC32_IN
PC15-OSC32_OUT.Signal=RCC_OSC32_OUT
PC4.GPIO_Label=sdcard cs
PC4.Signal=GPIO_Output
PC6.GPIO_Label=hwen
PC6.Signal=GPIO_Output
PF0-OSC_IN.Signal=RCC_OSC_IN
PF1-OSC_OUT.Signal=RCC_OSC_OUT

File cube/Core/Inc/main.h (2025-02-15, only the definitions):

#define led_red_Pin GPIO_PIN_0
#define led_red_GPIO_Port GPIOA
#define led_blue_Pin GPIO_PIN_1
#define led_blue_GPIO_Port GPIOA
#define sdcard_cd_Pin GPIO_PIN_2
#define sdcard_cd_GPIO_Port GPIOA
#define sdcard_en_Pin GPIO_PIN_3
#define sdcard_en_GPIO_Port GPIOA
#define sdcard_cs_Pin GPIO_PIN_4
#define sdcard_cs_GPIO_Port GPIOA
#define chg_cur_Pin GPIO_PIN_0
#define chg_cur_GPIO_Port GPIOB
#define batt_info_Pin GPIO_PIN_1
#define batt_info_GPIO_Port GPIOB
#define bmp280_cs_Pin GPIO_PIN_10
#define bmp280_cs_GPIO_Port GPIOB
#define chg_ind_Pin GPIO_PIN_12
#define chg_ind_GPIO_Port GPIOB
#define chg_hi_Pin GPIO_PIN_13
#define chg_hi_GPIO_Port GPIOB
#define display_en_Pin GPIO_PIN_15
#define display_en_GPIO_Port GPIOB
#define display_cs_Pin GPIO_PIN_8
#define display_cs_GPIO_Port GPIOA
#define display_rs_dc_Pin GPIO_PIN_9
#define display_rs_dc_GPIO_Port GPIOA
#define display_rst_Pin GPIO_PIN_10
#define display_rst_GPIO_Port GPIOA
#define display_light_Pin GPIO_PIN_15
#define display_light_GPIO_Port GPIOA
#define btn_dn_Pin GPIO_PIN_7
#define btn_dn_GPIO_Port GPIOB
#define btn_dn_EXTI_IRQn EXTI9_5_IRQn
#define btn_sel_Pin GPIO_PIN_8
#define btn_sel_GPIO_Port GPIOB
#define btn_sel_EXTI_IRQn EXTI9_5_IRQn
#define btn_up_Pin GPIO_PIN_9
#define btn_up_GPIO_Port GPIOB
#define btn_up_EXTI_IRQn EXTI9_5_IRQn

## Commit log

2024-09-30 hw - схема
    [TSX-3225_16.0000MF18X-AC3.step, TYPE-C-31-M-12.step, sky-meter.kicad_pcb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]
2024-10-03 hm - доработана схема
    [NX3215SA-32.768K-STD-MUA-14.step, sky-meter.kicad_sch]
2024-10-05 разведена плата, надо проверять
    [sky-meter.kicad_pcb, sky-meter.kicad_sch]
2024-10-08 плата - доработана и отправлена в заказ v1.0
    [sky-meter.kicad_pcb, sky-meter.kicad_sch]
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2024-10-22 воркер (облегчённый, без shared_ptr)
2024-10-23 дисплей - основной функционал (стал использовать воркер, но теперь нет view-класса, только присвоение функции-рисовальщика)
2024-10-24 заготовка под отрисовку главной страницы
2024-10-24 инит часов - установка даты/времени компиляции прошивки
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2024-10-27 модальные окна меню - форма подтверждения
2024-10-28 конфиг с сохранением во внутренней flash, теперь надо делать правки в меню и тестировать сохранение конфига
2024-10-29 меню - пункты изменения основного конфига
2024-10-31 конфиг - сохранение во flash
2024-11-02 jmp - лог высоты
2024-11-03 меню - много разных функций
2024-11-04 модуль power - заготовка под энергосбережение... но надо сначала переосмыслить работу устр-ва через таймеры
2024-11-06 основной цикл - с применением rtc таймера, убираем воркер - jmp
2024-11-07 убираем воркер - дисплей, меню
2024-11-08 убираем воркер - кнопки
2024-11-08 управление энергосбережением (требуется отладка)
2024-11-09 управление энергосбережением - поправлены баги
2024-11-09 работа часов без сброса при отсутствии питания
2024-11-10 небольшие доработки по пинам - hwen, led
2024-11-10 толщина платы - для корректной модели для внутрянки корпуса
    [sky-meter.kicad_pcb]
2024-11-12 обработка батареи - требуется тестирование и отладка
2024-11-13 доработки по индикации батареи
2024-11-15 отключатели меню и графика прыжка
2024-11-16 корпус
    [sky-meter-down.stl, sky-meter-up.stl, sky-meter.FCStd]
2024-11-16 рефакторинг записи во внутреннюю флеш
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2024-11-17 логбук - отображение в меню
2024-11-17 отображение фатальных ошибок системы на красном светодиоде
2024-11-23 доработки по энергопотреблению и режимам сон/выкл
2024-11-23 баги и доработки длительностей этапов прыжка в логбуке
2024-11-23 реорганизация под разные контроллеры
2024-11-23 реорганизация под разные контроллеры - g473
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2024-11-24 реорганизация под разные контроллеры - доработки по g431
2024-11-24 доработки по спящему режиму и выходу в начале подъёма
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2024-12-01 поправлены параметры выхода из сна в начале подъёма
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2024-12-21 более быстрое (при удержании) изменение кол-ва прыжков в настройках
2024-12-21 логбук - переключение между прыжками внутри подробного инфо
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2024-12-30 рефакторинг altcalc - буфер высот вынесен в отдельный класс
2024-12-30 sd карта - несущественные доработки (пока ни на что не влияющие)
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2025-01-07 приложение - загрузка и отрисовка графика из файла
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2025-01-11 плата v2 - заменён проц на f4, доработки и баги с прошлой версии
    [sky-meter.kicad_pcb, sky-meter.kicad_sch]
2025-02-14 перемещаем код в cube - пока только корневые файлы
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2025-02-14 перенесён def.h, исправлены варнинги
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2025-02-15 переезд на stm32а411 - пины, временно отключен USB (с ним не стартует)
2025-02-15 доработки по bmp280 (на высокой частоте spi более 25МГц работает плохо)
2025-02-15 вернули usb (после перехода на f411 остались хвосты от g4 в Makefile)
2025-02-18 большая переработка взаимодействия с внутренней флеш, конфиг, логбук
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2025-02-20 попытка разобраться, почему перестала работать sd-карта (пока неуспешно)
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2025-03-03 немного переделан модуль работы с sd-картой + выяснилось, что все проблемы с определением были из-за плохого питания
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2025-04-14 отключение питания - переделано через обращение напрямую к регистрам, полный сброс всех пинов, удалось уменьшить потребление до 120 мкА
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2025-04-16 app - подключен и используется для отрисовки AltCalc
2025-04-17 app - вся математика в графиках переделана на матрицы
2025-04-17 app - курсор = отображение подробной инфы в определённой точке
2025-04-18 переработан модуль взаимодействия с bmp280 - код калькуляции взят максимально точно из datasheet
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2025-04-22 app - логбук - загрузка из папки (пока только сам логбук, без трассировок)
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2025-04-24 app - отрисовка графиков - переделана обратно на прямые безматричные вычисления - не смог добиться стабильного зума с привязкой к точке, если совмещать ещё с ручным перемещением.
2025-04-24 коммуникация с приложением - подключение и обмен командами
2025-04-25 app - получение с устройства логбука и трассировок
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2025-04-26 app - доработки по сборке jump(altcalc) по windows
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2025-04-27 hw - добавлен индикатор зарядки и транзистор на питание sd-карты
    [sky-meter.kicad_pcb, sky-meter.kicad_sch]
2025-05-11 барометр - страница с графиком изменения давления за 10 часов
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2025-06-08 box - версия с креплением на запястье
    [sky-meter-down-w.stl, sky-meter-up-w.stl, sky-meter.FCStd]
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2025-06-09 логбук - информация, есть ли трассировка к прыжку
2025-06-14 box - доработки краёв корпуса
    [sky-meter-down-w.stl, sky-meter-down.stl, sky-meter-h-down.stl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]
2025-06-22 доработки по инициализации sd-карты сразу после подачи питания
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

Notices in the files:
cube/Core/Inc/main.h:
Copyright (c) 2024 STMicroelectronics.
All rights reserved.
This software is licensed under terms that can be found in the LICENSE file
